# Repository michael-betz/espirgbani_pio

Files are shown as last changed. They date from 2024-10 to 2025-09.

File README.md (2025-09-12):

# The ESP32 Pinball RGB Animation clock

video of the clock in action

Display the time and animations on HUB75 LED panels.

  * Anti aliased fonts
  * Full unicode support (emojis!)
  * Python .ttf font converter tool
  * Alpha blending
  * Background shaders
  * USB-PD powered. Can drive the two 64 x 32 panels at full brightness. The LED turns on if PD negotiation succeeded. Otherwise the clock will run in low-power mode
  * Ambient light sensor

[Video of how it looks like](https://www.youtube.com/watch?v=0dwTC5q5t4M)

[Older writeup](http://yetifrisstlama.blogspot.com/2018/02/the-esp32-pinball-rgb-matrix-animation.html)

# Building
Needs [platform.io](https://platformio.org/) installed.

To install the toolchain and build the project:

```bash
$ pio run
```

Connect USB cable and upload the SPIFFS file system:

```bash
$ pio run -t uploadfs
```

Upload the firmware and show the serial console:

```bash
$ pio run -t upload -t monitor
```

# SD card instructions
Format as FAT32, then copy the following files:
  * `./settings.json`
  * `./animations.img`
  * `./fnt/{d}.fnt`

The .fnt files can be generated from .ttf files with `dev/font_converter.py`.

## `settings.json`
If this file does not exist or cannot be parsed, a new file with default settings will be created.

Once the clock is connected to the network, `settings.json` can be edited in the web-interface at `http://espirgbani.local/`.

```json
{
    "panel_io": {
        "CLK": 13,
        "R1": 22,
        "G1": 23,
        "B1": 21,
        "R2": 18,
        "G2": 19,
        "B2": 5,
        "A": 16,
        "B": 17,
        "C": 2,
        "D": 4,
        "E": 32,
        "LAT": 15,
        "OE_N": 33
    },
    "panel": {
        "test_pattern": true,
        "tp_brightness": 10,
        "low_power_brightness": 20,
        "is_clk_inverted": true,
        "clkm_div_num": 4,
        "max_frame_rate": 30,
        "is_gamma": false,
        "is_locked": true
    },
    "delays": {
        "font": 3600,
        "color": 600,
        "ani": 30,
        "shader": 400
    },
    "power": {
        "mode": 1,
        "offset": 0,
        "divider": 400,
        "max_limit": 100,
        "min_limit": 2,
        "day": {
            "h": 9,
            "m": 0,
            "p": 20
        },
        "night": {
            "h": 22,
            "m": 45,
            "p": 2
        }
    },
    "wifis": {
        "INSERT_SSID": "INSERT_PASSWORD"
    },
    "hostname": "espirgbani",
    "log_level":    {
        "*":    3,
        "httpd_sess":   2,
        "httpd_txrx":   2,
        "httpd_ws": 2,
        "httpd_server": 2,
        "httpd_parse":  2,
        "httpd":    2,
        "spi_master":   2,
        "vfs_fat":  2,
        "wifi": 2
    },
    "timezone": "CET-1CEST,M3.5.0,M10.5.0/3",
    "ntp_host": "pool.ntp.org"
}
```

### `panel_io` section
This section allows you to customize which pins are used on the ESP32 to connect to the panel pins.
The numbers are ESP32 GPIO numbers.

For example, if you run the test-pattern and notice that the red and green colors are swapped,
you can swap their pins on the ESP32 like so:

```json
    "panel_io": {
        "R1": 23,
        "G1": 22,
        "R2": 19,
        "G2": 18
    }
```

### `panel` section
Not all LED panels are the same. Here the timing parameters of the I2S panel driver can be configured.

  * `test_pattern`: if `true`, enters a LED panel test mode instead of normal operation
  * `tp_brightness`: brightness of the test pattern, from 1 to 127. Current draw gets ridiculous for the higher values
  * `low_power_brightness`: maximum brightness if USB-PD negotiation fails (if running from 5 V)
  * `is_clk_inverted`: if `false`, data changes on the rising clock edge. If `true`, data is stable on the rising clock edge (most panels need `true`)
  * `clkm_div_num`: sets the I2S clock divider from 2 to 128. Set it too high and get flicker, too low get ghost pixels. Flicker can be improved at the cost of color depth by reducing `BITPLANE_CNT` in `rgb_led_panel.h`.
  `"clkm_div_num": 4` corresponds to a 10 MHz pixel clock
  * `max_frame_rate`: the global maximum frame-rate limit in [Hz]. The background shader is updated at this rate. If the value is too large, freertos will become unresponsive
  * `is_gamma`: apply gamma correction to LED brightness
  * `is_locked`: stop screen updates while the clock numerals are written. Prevents tearing artifacts at the cost of a short freeze of the background shader

### `delays` section
controls delays between random animations, color and font changes.
They are all specified in [seconds]. The defaults are:

  * Randomize clock font every 3600 s (60 min)
  * Randomize outline color every 600 s (10 min)
  * Play a new pinball animation every 15 s
  * Randomize the background shader every 300 s (5 min). Set `shader` to <= 0 to always have a black background

### `power` section
controls the display brightness. Set the `mode` parameter to 0, 1 or 2 to select the control mode.

__mode 0: constant brightness__

Brightness is always the same and specified in `day.p` as a number from 0 to 127.

__mode 1: use ambient light sensor__

Brightness is set according to the measured ambient light. The sensor returns a number `x` from 0 - 4095 for a measured light level of roughly 10 - 1000 lux.

A linear equation is used to calculate the brightness: `p = (x - offset) / divider`.

The calculated value is limited to the range of `min_limit` to `max_limit` and applied as the panel brightness.

__mode 2: time based switching__

Brightness is set according to the current time. There is a `day` and `night` value, specified in `p` as a number from 0 to 127.

  * In the example, day-mode starts at `9:00` with brightness `20`
  * night-mode starts at `22:45` with brightness `2`

### `wifis` section
Add one or more wifi credentials. The key should be set to the SSID, the value to the wifi password.
If disconnected, the ESP will try to connect to the known wifi with the strongest signal every minute.

If the wifis section is empty or does not exist, the ESP will not try to connect to any wifis.

In any case, push the button on the PCB for > 1 s to toggle between Access Point and station mode.

### `hostname`
The hostname, which is the address where the ESP is reachable from the browser, can be customized here.

### `log_level`
Configure the esp-idf logging library. The key is the logging tag or `*` for everything.

The value the logging level

  * 0 = no logging
  * 1 = errors
  * 2 = warning
  * 3 = info
  * 4 = debug

See https://docs.espressif.com/projects/esp-idf/en/stable/esp32/api-reference/system/log.html

### `timezone`
is the local timezone in [TZ format](https://www.gnu.org/software/libc/manual/html_node/TZ-Variable.html). Look it up [here](https://github.com/nayarsystems/posix_tz_db/blob/master/zones.csv).

### `ntp_host`
The server used for time synchronization.

# TODO
  * fix hardware errors (4 botch wires), use MMC pins for SD card
  * http API support (easy use from curl)
  * wifi button support (access point on button press)
  * mqtt support?
  * update image from serial terminal

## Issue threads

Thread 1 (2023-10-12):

Timezone / settings ?

bipsendk, 2023-10-12:
Trying to understand the settings.json and how it is used in the source....

I cannot locate the place, where the timezone is being used - could you point me in the right direction ?

Also - I think it could be cool if the code was ablt to talk to a MQTT broker, so that some settings could be adjust that way around (e.g. adjusting the brightness of the display).

yetifrisstlama, 2023-10-13:
The timezone setting is a bit hidden in the esp-comms dependency:
https://github.com/yetifrisstlama/esp-comms/blob/f0fe37adfbb356d634fa6ac78435a4e0bac2f3d0/lib/esp-comms/esp_comms.cpp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

Some info on how the ESP handles timezones is given here:
https://docs.espressif.com/projects/esp-idf/en/latest/esp32/api-reference/system/system_time.html#timezones

Mqtt would indeed be pretty sweet to have, also to display short messages.

bipsendk, 2023-10-13:
Thanks - that got me a bit of info...

I'm no expert in programming myself, but if MQTT at some point would be added, I guess it is a question of being able to specify MQTT server/port - and create the required stuff for the device having auto-discoverable properties.
This would make the project more attractive for people with smarthome setups :-)

Closed 2023-11-01.

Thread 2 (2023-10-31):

Artifacts on panel

bipsendk, 2023-10-31:
The artifacts as seen on the attached picture - are they to be expected, or should I try to increase the blanks value in the json file?

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

michael-betz, 2023-11-01:
Hi bipsendk, glad to see you got the code running :)

I've noticed the same kind of ghosting on my panels when driven at maximum brightness.
My solution was to mount the panels behind some tinted acrylic, which makes the ghosting much less visible.

Maybe it can be fixed in the signal generation by putting some dead-time in the right place. Unfortunately I don't have the hardware setup right now to try that out.

You can also try playing with the parameters in the settings.json:

  * Reduce the brightness with `power.day.p` and `power.night.p`
  * Increase `extra_blank`, but I think I remember this didn't have an effect on my panels
  * Increase `clkm_div_num` to lower the output clock frequency
  * If you get flicker, you can try to reduce `BITPLANE_CNT` in rgb_led_panel.h to lower color resolution and increase refresh rate

Good luck and let me know how it goes,
Michael

bipsendk, 2023-11-01:
I will try to adjust brightness - but not quite sure if that will resolve the issue (just make it less visible).
Anyway - as I am not the only one seeing it, it is not something related directly to my hardware - so far, so good,

On the other hand, when trying to connect to the web interface, I get http error 500 .. I am using the IP address in the URL, not the hostname - but I guess that shouldn't be a problem.
Can it be an issue with the json config file ? I have not yet tried to remove it, to see if that changes anything.
Is it possible to add more logging a compile time - so I can get a hint on what is going on - and perhaps where in the code ?

michael-betz, 2023-11-02:
Hmm that's a strange one. Just to be sure, did you flash the filesystem?
```bash
$ pio run -t uploadfs
```

bipsendk, 2023-11-02:
That was the missing thing... As I am using pio via VSCode on Windows, I expected that to happen during the upload of the firmware - but apparently that needs to be handled as a separate task. Thanks

michael-betz, 2025-01-07:
The ghosting issue is completely resolved now in the current version of the software. This was done by enabling the LEDs (setting the /OE signal low) in the middle of the frame update cycle instead of at the beginning / end. This maximizes the delay between the edge of the Latch pulse and the /OE low period, giving the signals on the panel some time to stabilize.

Closed 2023-11-02.

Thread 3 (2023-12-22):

LDR / Photo resistor

bipsendk, 2023-12-22:
Is the LDR / Photo resistor still supported in the new version of the software ?

As multiple versions exists of LDR (different values), I guess some sort of "calibration" will have to be done - unless you are sure to get the right LDR ?

michael-betz, 2025-01-07:
The ambient light sensor is supported now in the software. See power-mode 1 in the [README.md](https://github.com/michael-betz/espirgbani_pio#power-section)

Closed 2025-01-07.

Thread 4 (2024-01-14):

Pin re-assignment

bipsendk, 2024-01-14:
For the HUB75 connection - is it possible to swap the different pins in the header file - to better suit the pinout of a Wemos D1 ESP32 ? - or is special attention needed on some of the pins ?

Closed 2024-12-27.

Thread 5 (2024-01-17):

Newer framework when compiling

bipsendk, 2024-01-17:
I have managed to get the code compiled on a newer framework, also with the fseek "hack"/optimizartion enabled in the framework.

One issue remains, though - it seems like the partitions.bin file isn't created.

I am not sure what part actually creates this one.

for lib_deps I have had to change to this - not sure if that affects the generation of the data:

```
lib_deps =
	https://github.com/me-no-dev/AsyncTCP.git
	https://github.com/me-no-dev/ESPAsyncWebServer.git
	https://github.com/yetifrisstlama/esp-comms.git

```

Let me know if I should share the modified files

bipsendk, 2024-01-18:
FYI - the result of the build with the newer framework - not quite sure why it cannot read the SD card, as it works OK with the same framework for the fseek test:

```
I (29) boot: ESP-IDF 4.4.6 2nd stage bootloader
I (29) boot: compile time 20:34:44
I (29) boot: Multicore bootloader
I (32) boot: chip revision: v3.0
I (36) boot.esp32: SPI Speed      : 40MHz
I (41) boot.esp32: SPI Mode       : DIO
I (45) boot.esp32: SPI Flash Size : 4MB
I (50) boot: Enabling RNG early entropy source...
I (55) boot: Partition Table:
I (59) boot: ## Label            Usage          Type ST Offset   Length
I (66) boot:  0 nvs              WiFi data        01 02 00009000 00005000
I (73) boot:  1 otadata          OTA data         01 00 0000e000 00002000
I (81) boot:  2 app0             OTA app          00 10 00010000 00140000
I (88) boot:  3 app1             OTA app          00 11 00150000 00140000
I (96) boot:  4 spiffs           Unknown data     01 82 00290000 00160000
I (103) boot:  5 coredump         Unknown data     01 03 003f0000 00010000
I (111) boot: End of partition table
I (115) esp_image: segment 0: paddr=00010020 vaddr=3f400020 size=215b0h (136624) map
I (173) esp_image: segment 1: paddr=000315d8 vaddr=3ffb0000 size=032b4h ( 12980) load
I (179) esp_image: segment 2: paddr=00034894 vaddr=40080000 size=0b784h ( 46980) load
I (198) esp_image: segment 3: paddr=00040020 vaddr=400d0020 size=ad920h (710944) map
I (456) esp_image: segment 4: paddr=000ed948 vaddr=4008b784 size=09b6ch ( 39788) load
I (483) boot: Loaded app from partition at offset 0x10000
I (483) boot: Disabling RNG early entropy source...
I (494) cpu_start: Multicore app
I (495) cpu_start: Pro cpu up.
I (495) cpu_start: Starting app cpu, entry point is 0x40081d84
I (485) cpu_start: App cpu up.
I (515) cpu_start: Pro cpu start user code
I (515) cpu_start: cpu freq: 160000000
I (515) cpu_start: Application information:
I (519) cpu_start: Project name:     espirgbani_pio-master-NEW
I (526) cpu_start: App version:      1
I (530) cpu_start: Compile time:     Jan 17 2024 20:30:37
I (536) cpu_start: ELF file SHA256:  57173bc45eb927f1...
I (542) cpu_start: ESP-IDF:          4.4.6
I (547) cpu_start: Min chip rev:     v0.0
I (552) cpu_start: Max chip rev:     v3.99
I (557) cpu_start: Chip rev:         v3.0
I (562) heap_init: Initializing. RAM available for dynamic allocation:
I (569) heap_init: At 3FFAE6E0 len 00001920 (6 KiB): DRAM
I (575) heap_init: At 3FFC5A00 len 0001A600 (105 KiB): DRAM
I (581) heap_init: At 3FFE0440 len 00003AE0 (14 KiB): D/IRAM
I (587) heap_init: At 3FFE4350 len 0001BCB0 (111 KiB): D/IRAM
I (594) heap_init: At 400952F0 len 0000AD10 (43 KiB): IRAM
I (601) spi_flash: detected chip: generic
I (605) spi_flash: flash io: dio
I (611) cpu_start: Starting scheduler on PRO CPU.
I (0) cpu_start: Starting scheduler on APP CPU.
[    49][W][main.cpp:71] setup(): reset reason: 12, heap: 211120, min_heap: 211112
I (207) gpio: GPIO[33]| InputEn: 1| OutputEn: 1| OpenDrain: 0| Pullup: 0| Pulldown: 0| Intr:0
I (208) gpio: GPIO[35]| InputEn: 1| OutputEn: 0| OpenDrain: 0| Pullup: 0| Pulldown: 0| Intr:0
I (216) gpio: GPIO[32]| InputEn: 1| OutputEn: 1| OpenDrain: 0| Pullup: 0| Pulldown: 0| Intr:0
I (225) gpio: GPIO[14]| InputEn: 1| OutputEn: 1| OpenDrain: 0| Pullup: 0| Pulldown: 0| Intr:0
[   256][E][json_settings.cpp:53] readFileDyn(): fopen(/sd/settings.json, rb) failed: Invalid argument
[   258][W][json_settings.cpp:128] set_settings_file(): writing default-settings to /sd/settings.json
[   271][E][json_settings.cpp:136] set_settings_file(): could not copy /spiffs/default_settings.json to /sd/settings.json: Invalid argument
[   282][E][json_settings.cpp:53] readFileDyn(): fopen(/sd/settings.json, rb) failed: Invalid argument
[   292][E][json_settings.cpp:164] jGetI(): max_frame_rate is not a number, falling back to 30
[   301][E][json_settings.cpp:184] jGetB(): column_swap is not a bool, falling back to false
[   310][E][json_settings.cpp:164] jGetI(): latch_offset is not a number, falling back to 0
[   319][V][rgb_led_panel.cpp:76] init_rgb(): latch_offset = 127
[   325][E][json_settings.cpp:164] jGetI(): extra_blank is not a number, falling back to 1
[   334][E][json_settings.cpp:164] jGetI(): clkm_div_num is not a number, falling back to 4
[   343][V][rgb_led_panel.cpp:84] init_rgb(): clkm_div_num = 4
[   350][E][json_settings.cpp:184] jGetB(): is_clk_inverted is not a bool, falling back to true
[   360][I][rgb_led_panel.cpp:124] init_rgb(): I2S setup done.
[   375][E][json_settings.cpp:154] jGetS(): wifi_ssid is not a string, falling back to RG47C-0
[   375][E][json_settings.cpp:154] jGetS(): hostname is not a string, falling back to ESP-PINBALL
[   385][E][json_settings.cpp:154] jGetS(): wifi_pw is not a string, falling back to DemsPi8!av63ippo#
I (385) wifi:wifi driver task: 3ffdd930, prio:23, stack:6656, core=0
I (1420) wifi:wifi firmware version: 1ba8b6a
I (1420) wifi:wifi certification version: v7.0
I (1421) wifi:config NVS flash: enabled
I (1421) wifi:config nano formating: disabled
I (1425) wifi:Init data frame dynamic rx buffer num: 32
I (1430) wifi:Init management frame dynamic rx buffer num: 32
I (1435) wifi:Init management short buffer num: 32
I (1440) wifi:Init dynamic tx buffer num: 32
I (1444) wifi:Init static rx buffer size: 1600
I (1448) wifi:Init static rx buffer num: 4
I (1452) wifi:Init dynamic rx buffer num: 32
I (1457) wifi_init: rx ba win: 6
I (1460) wifi_init: tcpip mbox: 32
I (1464) wifi_init: udp mbox: 6
I (1468) wifi_init: tcp mbox: 6
I (1471) wifi_init: tcp tx win: 5744
I (1476) wifi_init: tcp rx win: 5744
I (1480) wifi_init: tcp mss: 1440
I (1484) wifi_init: WiFi IRAM OP enabled
I (1489) wifi_init: WiFi RX IRAM OP enabled
[   491][D][WiFiGeneric.cpp:1039] _eventCallback(): Arduino Event: 0 - WIFI_READY
I (1503) phy_init: phy_version 4771,450c73b,Aug 16 2023,11:03:10
I (1584) wifi:mode : sta (a0:b7:65:62:ed:98)
I (1585) wifi:enable tsf
00;3;377mm[[      558683]][[VV][][WWiiFiFiGGeenenerriicc..cpcppp::9734]0 ]s e_ta_redsupi_nion_teervfeanct_cb()) SCA Stgrreng 0ta
[   589][D][WiFiGeneric.cpp:1039] _eventCallback(): Arduino Event: 2 - STA_START
tion static IP: 0.0.0.0, MASK: 0.0.0.0, GW: 0.0.0.0
I (1600) wifi:Set ps type: 1

[   607][I][esp_comms.cpp:104] init_comms(): This is ESP-PINBALL, connecting to RG47C-0
I (1616) gpio: GPIO[0]| InputEn: 1| OutputEn: 0| OpenDrain: 0| Pullup: 1| Pulldown: 0| Intr:0
I (1622) wifi:new:<9,0>, old:<1,0>, ap:<255,255>, sta:<9,0>, prof:1
I (1633) wifi:state: init -> auth (b0)
I (1637) wifi:state: auth -> assoc (0)
I (1644) wifi:state: assoc -> run (10)
I (1663) wifi:connected with RG47C-0, aid = 22, channel 9, BW20, bssid = 28:c7:ce:1e:f8:c0
I (1664) wifi:security: WPA2-PSK, phy: bgn, rssi: -62
I (1670) wifi:pm start, type: 1

I (1673) wifi:<ba-add>idx:0 (ifx:0, 28:c7:ce:1e:f8:c0), tid:0, ssn:2612, winSize:64
[   669][V][WiFiGeneric.cpp:355] _arduino_event_cb(): STA Connected: SSID: RG47C-0, BSSID: 28:c7:ce:1e:f8:c0, Channel: 9, Auth: WPA2_PSK
[   686][D][WiFiGeneric.cpp:1039] _eventCallback(): Arduino Event: 4 - STA_CONNECTED
I (1724) wifi:AP's beacon interval = 104448 us, DTIM period = 2
[  1691][V][WiFiGeneric.cpp:369] _arduino_event_cb(): STA Got New IP:192.168.225.153
[  1693][D][WiFiGeneric.cpp:1039] _eventCallback(): Arduino Event: 7 - STA_GOT_IP
[  1698][D][WiFiGeneric.cpp:1102] _eventCallback(): STA IP: 192.168.225.153, MASK: 255.255.255.0, GW: 192.168.225.202
0;32mI (2696) esp_netif_handlers: sta ip: 192.168.225.153, mask: 255.255.255.0, gw: 192.168.225.202
[  1723][I][esp_comms.cpp:115] init_comms(): Initializing SNTP
[  2725][E][json_settings.cpp:154] jGetS(): hostname is not a string, falling back to ESP-PINBALL
[  2725][E][json_settings.cpp:184] jGetB(): enable_ota is not a bool, falling back to false
[  2749][E][json_settings.cpp:154] jGetS(): timezone is not a string, falling back to PST8PDT
[  2749][I][esp_comms.cpp:144] init_comms(): Setting timezone to TZ = PST8PDT
[  2755][I][esp_comms.cpp:152] init_comms(): Local Time: Wed Jan 17 11:43:16 2024 (1705520596)
[  2764][W][main.cpp:93] setup(): after COMMS, heap: 100644, min_heap: 99668
[  2772][E][json_settings.cpp:184] jGetB(): test_pattern is not a bool, falling back to true
[  2781][W][main.cpp:101] setup(): RGB test-pattern mode!!!
[  2787][E][json_settings.cpp:164] jGetI(): tp_brightness is not a number, falling back to 10
[  2797][E][json_settings.cpp:164] jGetI(): tp_brightness is not a number, falling back to 10
[  2816][D][frame_buffer.cpp:206] tp_task(): Diagonal
Guru Meditation Error: Core  0 panic'ed (LoadStoreError). Exception was unhandled.

Core  0 register dump:
PC      : 0x400d9b47  PS      : 0x00060430  A0      : 0x800d9c66  A1      : 0x3ffe8450
A2      : 0x3ffe0454  A3      : 0x3ffe30c0  A4      : 0x401772a0  A5      : 0x00000000
A6      : 0x3ffe0454  A7      : 0x3ffe3968  A8      : 0x800d9bba  A9      : 0x3ffe8430
A10     : 0x3ffe30c0  A11     : 0x40000de8  A12     : 0x3ffe2abc  A13     : 0x3ffe3b9a
A14     : 0x0000000d  A15     : 0x00000000  SAR     : 0x0000001a  EXCCAUSE: 0x00000003
EXCVADDR: 0x40000df7  LBEG    : 0x400014fd  LEND    : 0x4000150d  LCOUNT  : 0xfffffffd

Backtrace: 0x400d9b44:0x3ffe8450 0x400d9c63:0x3ffe84b0 0x400d9d69:0x3ffe84f0 0x400d9f5d:0x3ffe8550 0x4015d519:0x3ffe8570 0x4015d56d:0x3ffe85a0 0x4015d5b1:0x3ffe85c0 0x4015d76e:0x3ffe85e0 0x4015d83f:0x3ffe8600 0x4008c3a1:0x3ffe8630
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

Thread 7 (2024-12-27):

PCB - add connectors for external USB / SD-card ?

bipsendk, 2024-12-27:
Regarding the "new" version of the PCB - have you considered adding e.g. JST-XH header for "external" USB connector (6-pin) - and JST-PH header for using an "external" SD-Card PCB (arduino-style) ? That will increase flexibility if/when using the PCB with different sizes of HUB75 panels and placing them inside a 3D printed enclosure.

bipsendk, 2024-12-28:
Like this:
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

michael-betz, 2025-01-07:
Ahh interesting idea! Feel free to implement it, using the existing layout as a starting point.

The new PCB was especially designed to fit nicely right into the typical P2.5 panels.

Another idea to gain some flexibility is to solder a right-angled pin header on the PCB and then use the flat cable which comes with the panels to connect them to the PCB.

bipsendk, 2025-01-23:
The comment in to-do about changing pins for the SDcard - would that be to GPIO 12/13/14/15 for the MOSI/MISO/CLK/CS - or 5/18/19/23  ?
As far as I remember, there was a challenge with pin 12 during boot ?

michael-betz, 2025-01-23:
Hi,

you can have a look at the schematic in the REV3 branch:

https://github.com/michael-betz/espirgbani_pio/blob/rev3/pcb/pdf/rgb.pdf

I've chosen the pins to make use of the SD-MMC block in the chip.

I've convinced myself that this should work out of the box in 2-wire mode.
But please review!

For 4-wire mode, the pullup on GPIO12 needs to be added __after__ the efuse in the ESP32 has been burned for 3.3 V flash operation.

bipsendk, 2025-02-09:
Just wondering - would an ESP32-S3 be able to run the code? It comes in versions with more GPIO pins, and if more pins were available, perhaps a battery-backed RTC chip/module could be added to the setup to make sure the clock also could/would run in case of lack of internet access upon bootup.

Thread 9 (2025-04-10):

Ambient light sensor

bipsendk, 2025-04-10:
I am looking at the rev 3 code, and wonder a bit about the ambient light sensor...

	// 8x mode, actually 0 .. 32k now
	//   10 lux,   3 uA, 0.03 V,   50, Twilight, candle light
	//   50 lux,         0.17 V,  284, Street light at night
	//  100 lux,  33 uA, 0.33 V,  550, Dark museum
	// 1000 lux, 330 uA, 3.30 V, 4095, Bright office lightning

If 100 lux will let 33 uA pass - and the resistor is 24K - wouldn't the voltage be like 0.792V - and not 0.33V ?

The reason is, that listed ambient light sensor is a bit hard to find at a reasonable price at my location - where SIC433-02 is a bit easier to get.
That sensor has typically 220uA at 100lux - so in order to match 0.33V (if correct) would have to use a 1.5K resistor, and if matching 0.792V the resistor would have to be 3.6K ...

To get 0.33V with 33uA, the resistor would have to be 10K - or am I missing something ?

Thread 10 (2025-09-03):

FR: Disable PD pin

bipsendk, 2025-09-03:
In case you use "external" power decoy, the power good signal may not be avilable.

Would it be possible to modify the code in such a way, that of if GPIO_PD_BAD is not defined in common.h - then this "input" would not be used in the code

bipsendk, 2025-09-08:
But will there still be a risk, that the LPWR text will be triggered ?

Closed 2025-09-08.

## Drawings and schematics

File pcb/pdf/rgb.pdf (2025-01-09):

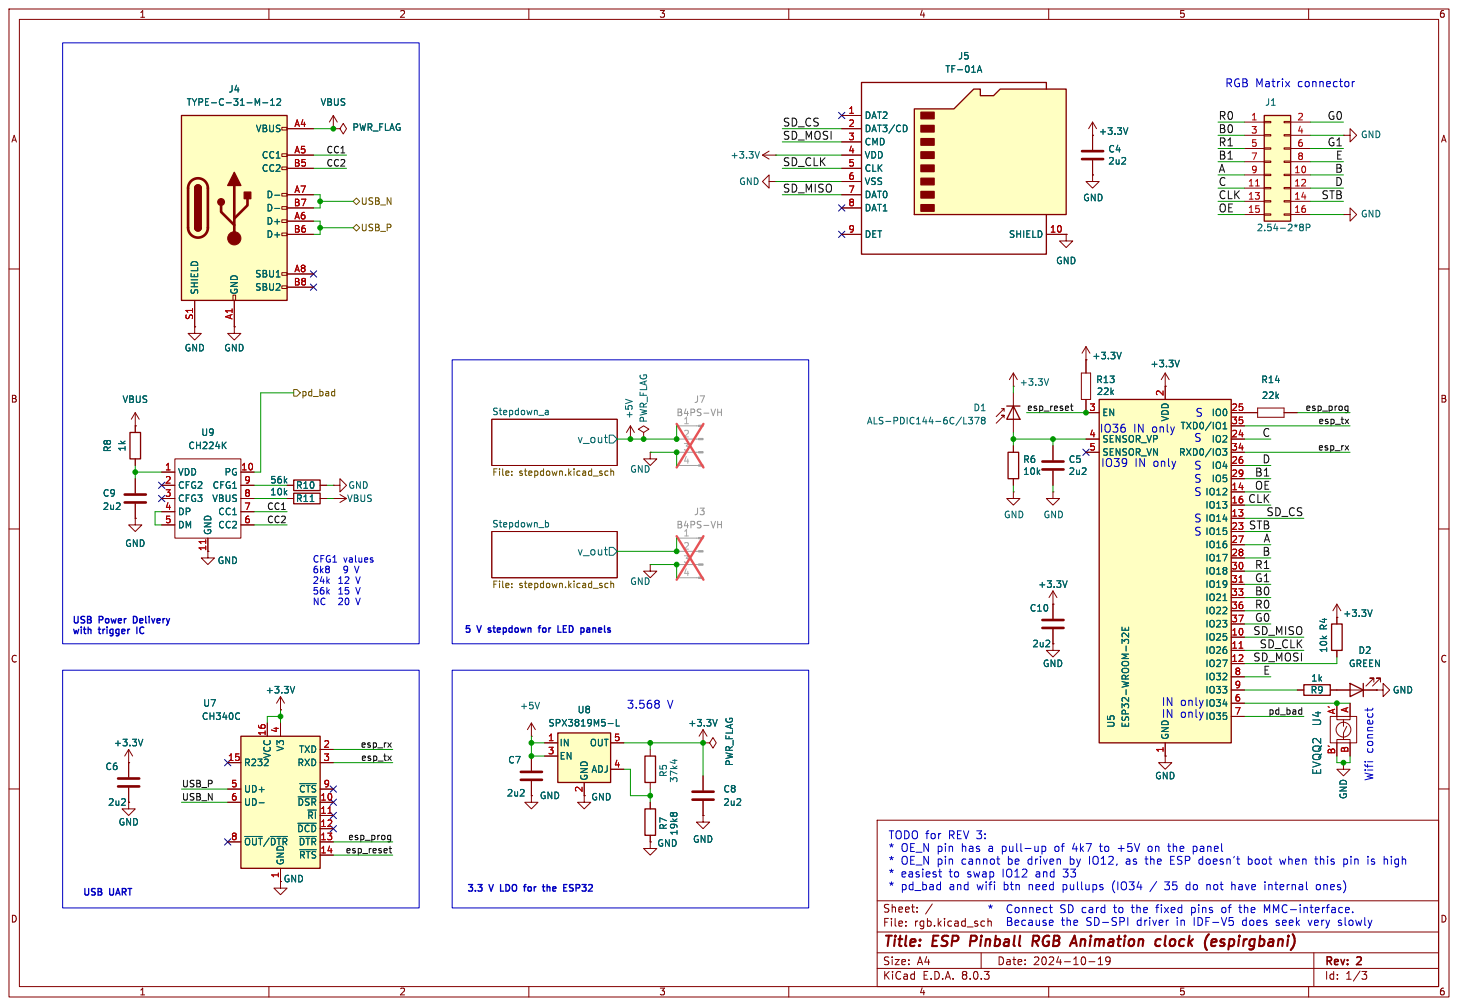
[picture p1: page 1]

5 V stepdown for LED panels R11 10k U9 CH224K

4 UD+ 5 UD- 6 ~{OUT}/~{DTR} 8 ~{CTS}9 U7 CH340C GND GND

2 EN 3 ADJ 4 OUT 5 U8 SPX3819M5-L GND

1 ~{DSR} 10 ~{RI} 11 ~{DCD} 12 ~{DTR} 13 ~{RTS} 14 R232 15 VCC 16 TXD 2 RXD 3 V3

4 UD+ 5 UD- 6 ~{OUT}/~{DTR} 8 ~{CTS}9 +3.3V C6

2 EN 3 ADJ 4 OUT 5 GND

* easiest to swap IO12 and 33

Id: 1/3 Title: ESP Pinball RGB Animation clock (espirgbani) File: rgb.kicad_sch Sheet: /

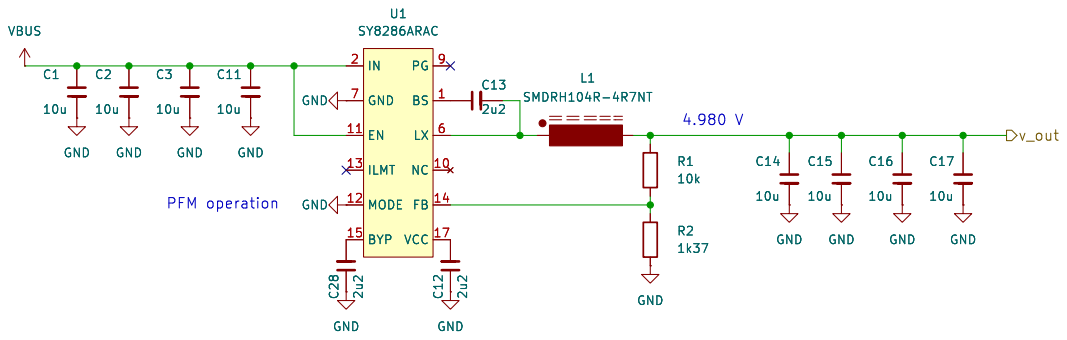
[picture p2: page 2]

Id: 2/3 Title: File: stepdown.kicad_sch Sheet: /Stepdown_a/

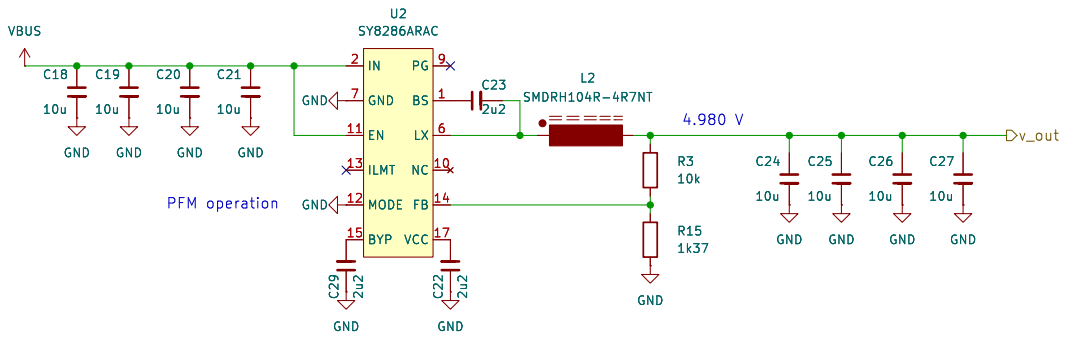
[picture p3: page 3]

Id: 3/3 Title: File: stepdown.kicad_sch Sheet: /Stepdown_b/

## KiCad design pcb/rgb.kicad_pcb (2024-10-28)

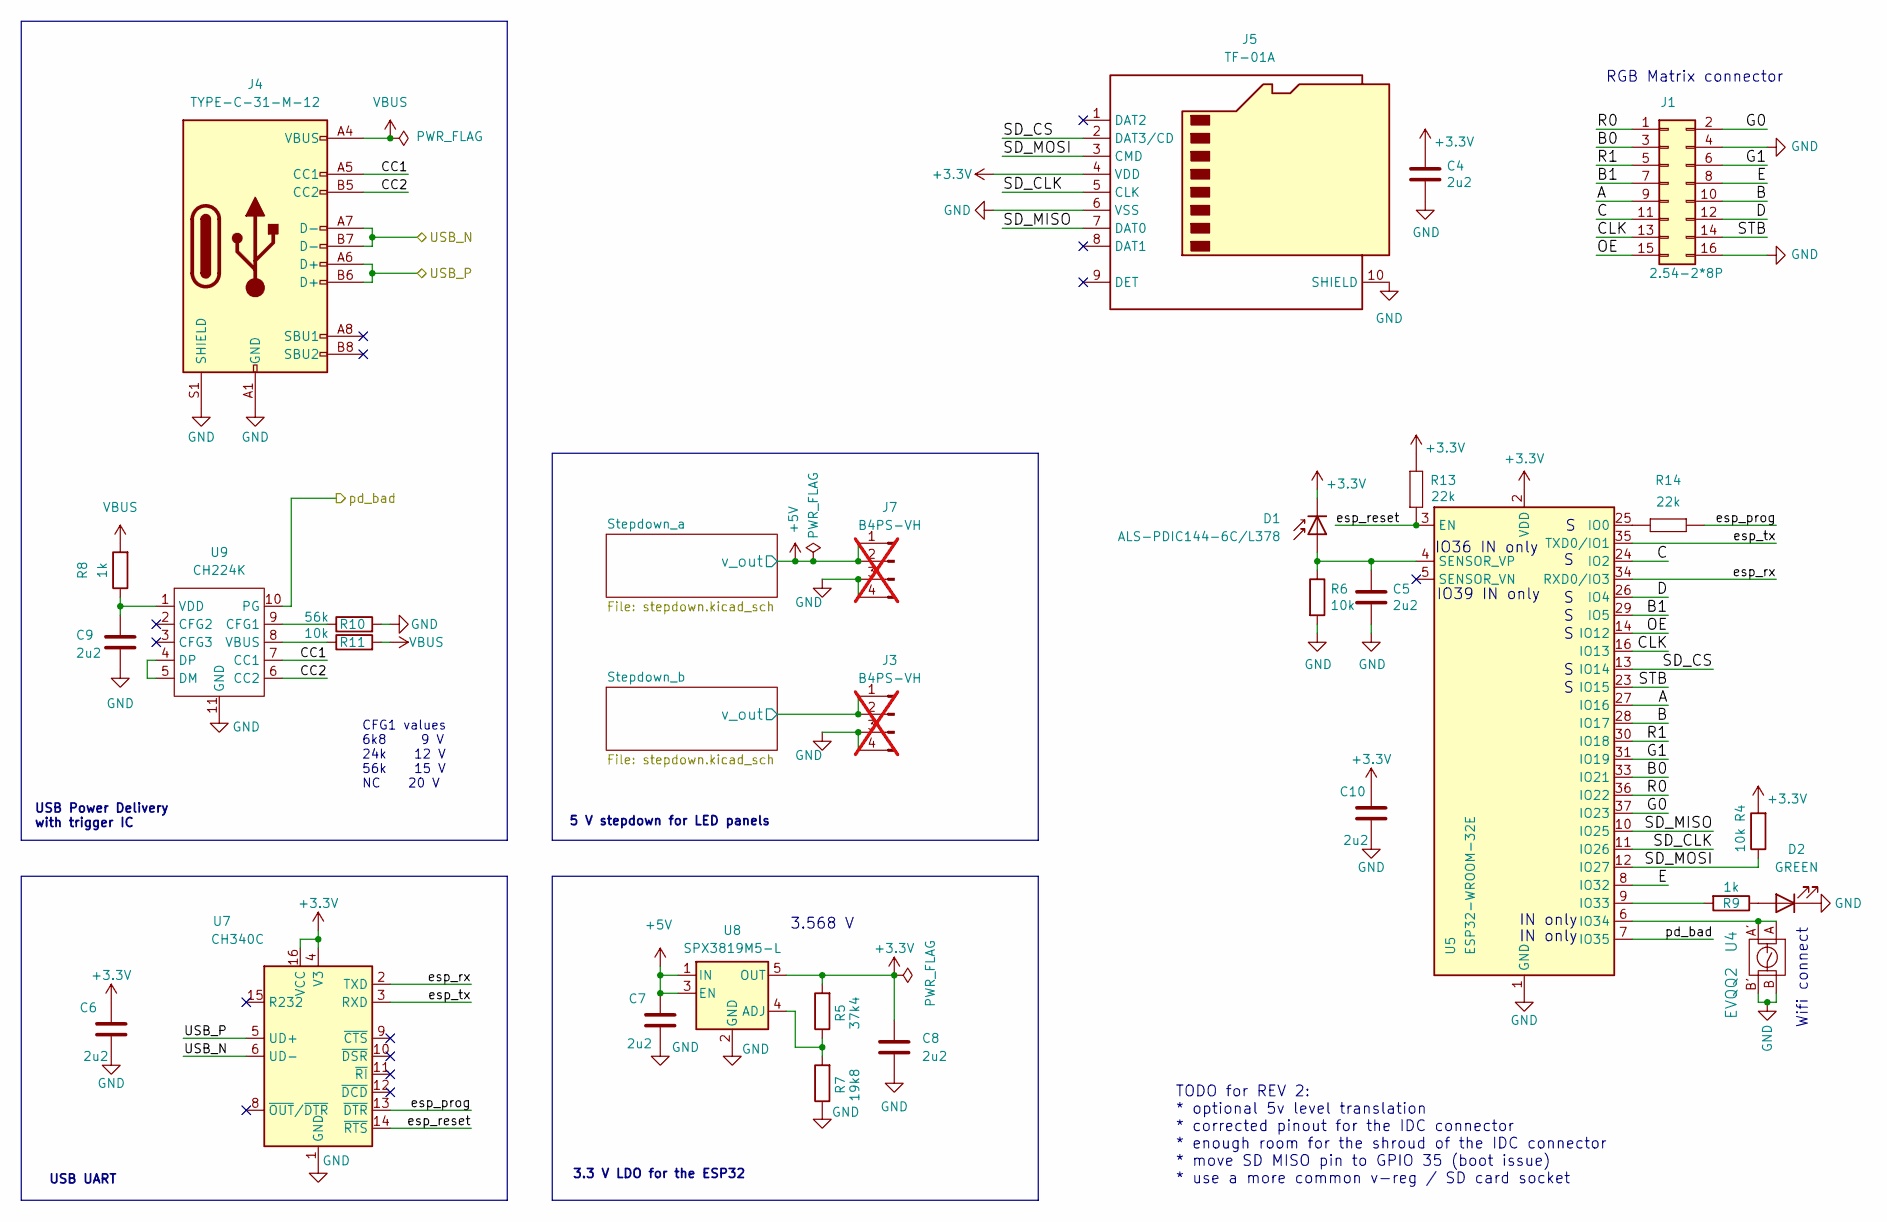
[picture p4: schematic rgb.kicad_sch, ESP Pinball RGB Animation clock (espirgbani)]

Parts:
C4, C5, C6, C7, C8, C9, C10: 2u2; C_0603_1608Metric
D1: ALS-PDIC144-6C/L378; LED_D3.0mm_Horizontal_O3.81mm_Z6.0mm
D2: GREEN; LED_0603_1608Metric
J1: 2.54-2*8P; PinSocket_2x08_P2.54mm_Vertical
J3, J7: B4PS-VH; PinSocket_1x04_P2.54mm_Vertical; JLCPN C157996; not fitted
J4: TYPE-C-31-M-12; USB_C_Receptacle_GCT_USB4105-xx-A_16P_TopMnt_Horizontal
J5: TF-01A
R4, R6, R11: 10k; R_0603_1608Metric
R5: 37k4; R_0603_1608Metric
R7: 19k8; R_0603_1608Metric
R8, R9: 1k; R_0603_1608Metric
R10: 56k; R_0603_1608Metric
R13, R14: 22k; R_0603_1608Metric
U4: EVQQ2
U5: ESP32-WROOM-32E; ESP32-WROOM-32D
U7: CH340C; SOIC-16_3.9x9.9mm_P1.27mm
U8: SPX3819M5-L; SOT-23-5
U9: CH224K; SSOP-10-1EP_3.9x4.9mm_P1.00mm

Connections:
+3.3V: C4.1, C6.2, C8.1, C10.2, D1.1 (K), J5.4 (VDD), R4.2, R5.2, R13.2, U5.2 (VDD), U7.4 (V3), U7.16 (VCC), U8.5 (OUT)
+5V: C7.2, J7.1, J7.2, U8.1 (IN), U8.3 (EN); also elsewhere on the board
/A: J1.9, U5.27 (IO16)
/B: J1.10, U5.28 (IO17)
/B0: J1.3, U5.33 (IO21)
/B1: J1.7, U5.29 (IO5)
/C: J1.11, U5.24 (IO2)
/CC1: J4.A5 (CC1), U9.7 (CC1)
/CC2: J4.B5 (CC2), U9.6 (CC2)
/CLK: J1.13, U5.16 (IO13)
/D: J1.12, U5.26 (IO4)
/E: J1.8, U5.8 (IO32)
/G0: J1.2, U5.37 (IO23)
/G1: J1.6, U5.31 (IO19)
/OE: J1.15, U5.14 (IO12)
/R0: J1.1, U5.36 (IO22)
/R1: J1.5, U5.30 (IO18)
/SD_CLK: J5.5 (CLK), U5.11 (IO26)
/SD_CS: J5.2 (DAT3/CD), U5.13 (IO14)
/SD_MISO: J5.7 (DAT0), U5.10 (IO25)
/SD_MOSI: J5.3 (CMD), R4.1, U5.12 (IO27)
/STB: J1.14, U5.23 (IO15)
/Stepdown_b/v_out: J3.1, J3.2; also elsewhere on the board
/USB_N: J4.A7 (D-), J4.B7 (D-), U7.6 (UD-)
/USB_P: J4.A6 (D+), J4.B6 (D+), U7.5 (UD+)
/esp_prog: R14.1, U7.13 (~DTR)
/esp_reset: R13.1, U5.3 (EN), U7.14 (~RTS)
/esp_rx: U5.34 (RXD0/IO3), U7.2 (TXD)
/esp_tx: U5.35 (TXD0/IO1), U7.3 (RXD)
/pd_bad: U5.7 (IO35), U9.10 (PG)
GND: C4.2, C5.2, C6.1, C7.1, C8.2, C9.2, C10.1, D2.1 (K), J1.4, J1.16, J3.3, J3.4, J4.A1 (GND), J4.A12 (GND), J4.B1 (GND), J4.B12 (GND), J4.S1 (SHIELD), J5.6 (VSS), J5.10 (SHIELD), J7.3, J7.4, R6.2, R7.1, R10.2, U4.B, U4.B', U5.1 (GND), U5.15 (GND), U5.38 (GND), U5.39 (GND), U7.1 (GND), U8.2 (GND), U9.11 (GND); also elsewhere on the board
unnamed: C5.1, D1.2 (A), R6.1, U5.4 (SENSOR_VP)
unnamed: D2.2 (A), R9.1
unnamed: R14.2, U5.25 (IO0)
unnamed: R9.2, U5.9 (IO33)
unnamed: U4.A, U4.A', U5.6 (IO34)
unnamed: R5.1, R7.2, U8.4 (ADJ)
unnamed: R10.1, U9.9 (CFG1)
unnamed: U9.4 (DP), U9.5 (DM)
unnamed: R11.1, U9.8 (VBUS)
unnamed: C9.1, R8.1, U9.1 (VDD)
VBUS: J4.A4 (VBUS), J4.A9 (VBUS), J4.B4 (VBUS), J4.B9 (VBUS), R8.2, R11.2; also elsewhere on the board

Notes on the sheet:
IO36 IN only
IN only
TODO for REV 2: * optional 5v level translation * corrected pinout for the IDC connector * enough room for the shroud of the IDC connector * move SD MISO pin to GPIO 35 (boot issue) * use a more common v-reg / SD card socket
USB Power Delivery with trigger IC
3.3 V LDO for the ESP32
CFG1 values 6k8 9 V 24k 12 V 56k 15 V NC 20 V
IO39 IN only
RGB Matrix connector
5 V stepdown for LED panels
3.568 V
Wifi connect
USB UART

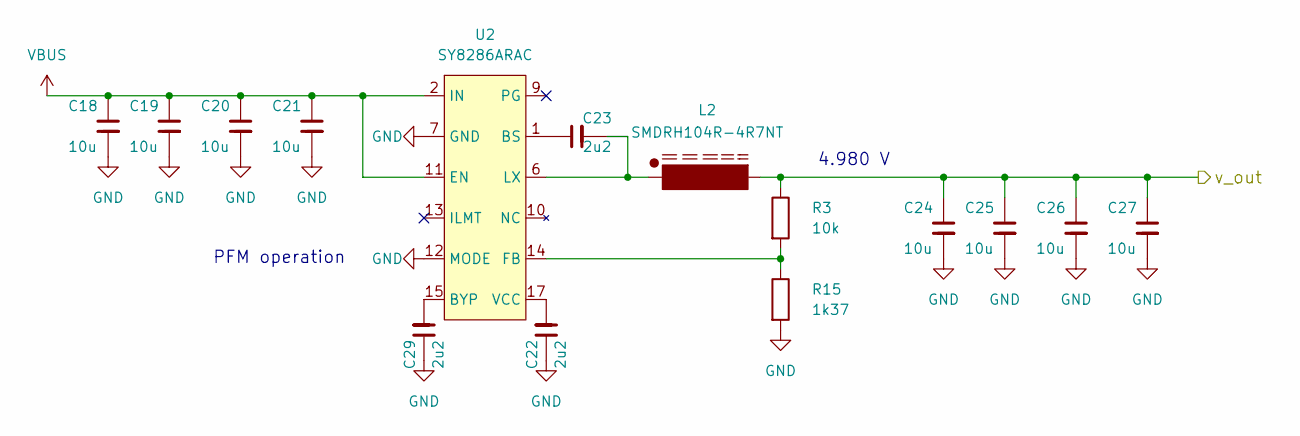
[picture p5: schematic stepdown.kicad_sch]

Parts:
C18, C19, C20, C21, C24, C25, C26, C27: 10u; C_1206_3216Metric; JLCPN C13585
C22, C23, C29: 2u2; C_0603_1608Metric
L2: SMDRH104R-4R7NT; JLCPN C44850
R3: 10k; R_0603_1608Metric
R15: 1k37; R_0603_1608Metric
U2: SY8286ARAC; QFN-20-1EP_3x3mm_P0.45mm_EP1.6x1.6mm

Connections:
/Stepdown_b/v_out: C24.2 (K), C25.2 (K), C26.2 (K), C27.2 (K), L2.1, R3.1; also elsewhere on the board
GND: C18.1 (A), C19.1 (A), C20.1 (A), C21.1 (A), C22.2 (K), C24.1 (A), C25.1 (A), C26.1 (A), C27.1 (A), C29.2 (K), R15.2, U2.7 (GND), U2.8 (GND), U2.12 (MODE), U2.18 (GND), U2.21 (GND); also elsewhere on the board
unnamed: C22.1 (A), U2.17 (VCC)
unnamed: C23.1 (A), L2.2, U2.6 (LX), U2.19 (LX), U2.20 (LX)
unnamed: C23.2 (K), U2.1 (BS)
unnamed: C29.1 (A), U2.15 (BYP)
unnamed: R3.2, R15.1, U2.14 (FB)
VBUS: C18.2 (K), C19.2 (K), C20.2 (K), C21.2 (K), U2.2 (IN), U2.3 (IN), U2.4 (IN), U2.5 (IN), U2.11 (EN); also elsewhere on the board

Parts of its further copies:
C1, C2, C3, C11, C14, C15, C16, C17: 10u; C_1206_3216Metric; JLCPN C13585
C12, C13, C28: 2u2; C_0603_1608Metric
L1: SMDRH104R-4R7NT; JLCPN C44850
R1: 10k; R_0603_1608Metric
R2: 1k37; R_0603_1608Metric
U1: SY8286ARAC; QFN-20-1EP_3x3mm_P0.45mm_EP1.6x1.6mm

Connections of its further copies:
+5V: C14.2 (K), C15.2 (K), C16.2 (K), C17.2 (K), L1.1, R1.1; also elsewhere on the board
GND: C1.1 (A), C2.1 (A), C3.1 (A), C11.1 (A), C12.2 (K), C14.1 (A), C15.1 (A), C16.1 (A), C17.1 (A), C28.2 (K), R2.2, U1.7 (GND), U1.8 (GND), U1.12 (MODE), U1.18 (GND), U1.21 (GND); also elsewhere on the board
unnamed: C12.1 (A), U1.17 (VCC)
unnamed: C13.1 (A), L1.2, U1.6 (LX), U1.19 (LX), U1.20 (LX)
unnamed: C13.2 (K), U1.1 (BS)
unnamed: C28.1 (A), U1.15 (BYP)
unnamed: R1.2, R2.1, U1.14 (FB)
VBUS: C1.2 (K), C2.2 (K), C3.2 (K), C11.2 (K), U1.2 (IN), U1.3 (IN), U1.4 (IN), U1.5 (IN), U1.11 (EN); also elsewhere on the board

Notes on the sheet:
4.980 V
PFM operation

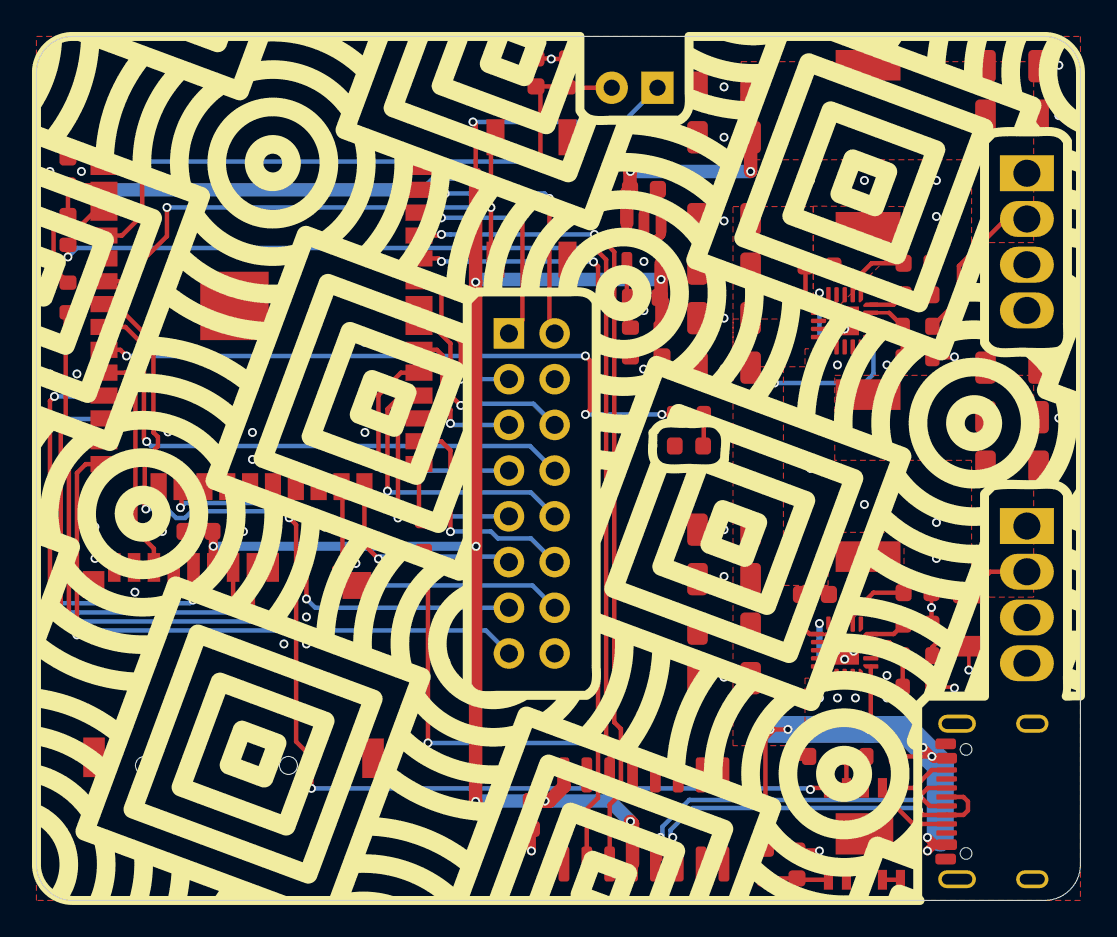
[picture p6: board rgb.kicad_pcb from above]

Board: 2 copper layers, 58.0 x 48.0 mm, 59 parts (1 on the bottom side), 52 nets.

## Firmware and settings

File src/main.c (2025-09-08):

// The ESP32 Pinball Animation Clock

#include "freertos/FreeRTOS.h"
#include "freertos/task.h"
#include "rom/rtc.h"
#include <dirent.h>
#include <errno.h>
#include <stdio.h>
#include <string.h>
#include <sys/types.h>

#include "driver/sdmmc_host.h"
#include "esp_http_server.h"
#include "esp_log.h"
#include "esp_spiffs.h"
#include "esp_vfs_fat.h"
#include "sdmmc_cmd.h"

#include "esp_wifi.h"
#include "json_settings.h"
#include "static_ws.h"
#include "wifi.h"

#include "animations.h"
#include "common.h"
#include "font.h"
#include "frame_buffer.h"
#include "rgb_led_panel.h"
#include "shaders.h"

static const char *T = "MAIN";

TaskHandle_t t_backg = NULL;
TaskHandle_t t_pinb = NULL;

static esp_err_t mount_sd_card(const char *path) {
	sdmmc_host_t host = SDSPI_HOST_DEFAULT();
	host.max_freq_khz = 26000; // [kHz]

	spi_bus_config_t bus_cfg = {
		.mosi_io_num = GPIO_SD_MOSI,
		.miso_io_num = GPIO_SD_MISO,
		.sclk_io_num = GPIO_SD_CLK,
		.quadwp_io_num = -1,
		.quadhd_io_num = -1,
	};
	ESP_ERROR_CHECK(spi_bus_initialize(host.slot, &bus_cfg, SDSPI_DEFAULT_HOST)
	);
	gpio_pullup_en(GPIO_SD_MISO);
	gpio_pullup_en(GPIO_SD_CS);

	sdmmc_card_t *card = NULL;

	sdspi_device_config_t device_cfg = SDSPI_DEVICE_CONFIG_DEFAULT();
	device_cfg.gpio_cs = GPIO_SD_CS;
	device_cfg.host_id = host.slot;

	esp_vfs_fat_sdmmc_mount_config_t mount_config = {
		.format_if_mount_failed = true,
		.max_files = 4,
	};

	esp_err_t ret = esp_vfs_fat_sdspi_mount(
		"/sd", &host, &device_cfg, &mount_config, &card
	);

	// sdmmc_host_t host = SDMMC_HOST_DEFAULT();
	// sdmmc_slot_config_t slot_config = SDMMC_SLOT_CONFIG_DEFAULT();
	// slot_config.width = 1;

	// slot_config.clk = GPIO_SD_CLK;
	// slot_config.cmd = GPIO_SD_MOSI;
	// slot_config.d0 = GPIO_SD_MISO;

	// // Enable internal pullups on enabled pins. The internal pullups
	// // are insufficient however, please make sure 10k external pullups are
	// // connected on the bus. This is for debug / example purpose only.
	// slot_config.flags |= SDMMC_SLOT_FLAG_INTERNAL_PULLUP;

	// ESP_LOGI(T, "Mounting filesystem");
	// ret = esp_vfs_fat_sdmmc_mount(mount_point, &host, &slot_config,
	// &mount_config, &card);

	// if (ret != ESP_OK) {
	//     if (ret == ESP_FAIL) {
	//         ESP_LOGE(T, "Failed to mount filesystem. ")
	//     } else {
	//         ESP_LOGE(T, "Failed to initialize the card (%s). ",
	//         esp_err_to_name(ret));
	//         // check_sd_card_pins(&config, pin_count);
	//     }
	//     return;
	// }

	if (ret == ESP_OK) {
		// Card has been initialized, print its properties
		sdmmc_card_print_info(stdout, card);
	} else {
		ESP_LOGE(
			T, "Failed to mount SD card. Continuing in test-pattern mode."
		);
	}
	return ret;
}

void list_files(const char *path) {
	ESP_LOGI(T, "Listing %s", path);
	DIR *dir = opendir(path);
	if (dir == NULL)
		return;

	while (true) {
		struct dirent *de = readdir(dir);
		if (!de)
			break;
		ESP_LOGI(T, "    %s", de->d_name);
	}

	closedir(dir);
}

void init_log() {
	const cJSON *jLog = NULL;
	const cJSON *jLogs = jGet(getSettings(), "log_level");

	cJSON_ArrayForEach(jLog, jLogs) {
		if (!cJSON_IsNumber(jLog)) {
			ESP_LOGW(T, "log_level: ignoring %s (not an int)", jLog->string);
			continue;
		}
		esp_log_level_set(jLog->string, jLog->valueint);
	}
}

// This handles websocket traffic, needs ESP-IDF > 4.2.x
static esp_err_t ws_handler(httpd_req_t *req) {
	static char ret_buffer[64];
	int ret_len = -1;

	if (req->method == HTTP_GET) {
		ESP_LOGI(T, "WS handshake");
		return ESP_OK;
	}

	// Copy the received payload into local buffer
	httpd_ws_frame_t wsf = {0};
	esp_err_t ret = httpd_ws_recv_frame(req, &wsf, 0);
	if (ret != ESP_OK)
		return ret;

	wsf.payload = malloc(wsf.len);
	if (!wsf.payload)
		return ESP_ERR_NO_MEM;

	ret = httpd_ws_recv_frame(req, &wsf, wsf.len);
	if (ret != ESP_OK) {
		free(wsf.payload);
		return ret;
	}

	if (wsf.type == HTTPD_WS_TYPE_TEXT && wsf.len > 0) {
		// Process the payload
		ESP_LOGV(T, "ws_callback(%c, %d)", wsf.payload[0], wsf.len);
		switch (wsf.payload[0]) {
		case 'a':
			if (wsf.len > 1 && wsf.payload[1] == '1')
				// dump complete log buffer
				wsDumpRtc(req, true);
			else
				// dump updates only
				wsDumpRtc(req, false);
			break;

		case 'b':
			// read / write settings.json
			settings_ws_handler(req, &wsf.payload[1], wsf.len - 1);
			if (wsf.len > 1)
				init_log();
			break;

		case 'r':
			esp_wifi_disconnect();
			set_brightness(0);
			vTaskDelay(100 / portTICK_PERIOD_MS);
			esp_restart();
			break;

		case 'h':
			ret_len = snprintf(
				ret_buffer, sizeof(ret_buffer),
				"h{\"heap\": %ld, \"min_heap\": %ld}", esp_get_free_heap_size(),
				esp_get_minimum_free_heap_size()
			);
			break;
		}
	}
	free(wsf.payload);

	// Send reply if needed
	if (ret_len >= 0) {
		if (ret_len > sizeof(ret_buffer))
			ret_len = sizeof(ret_buffer);

		httpd_ws_frame_t ret_wsf = {0};
		ret_wsf.type = HTTPD_WS_TYPE_TEXT;
		ret_wsf.payload = (uint8_t *)ret_buffer;
		ret_wsf.len = ret_len;
		httpd_ws_send_frame(req, &ret_wsf);
	}
	return ESP_OK;
}

void app_main(void) {
	// forward serial characters to web-console
	web_console_init();

	//------------------------------
	// init hardware
	//------------------------------
	// Power LED will be enabled by updateFrame loop if PD is not bad
	gpio_config_t cfg_o = {
		.pin_bit_mask = (1LL << GPIO_LED), .mode = GPIO_MODE_OUTPUT
	};
	ESP_ERROR_CHECK(gpio_config(&cfg_o));
	gpio_set_level(GPIO_LED, 0);

	// PD_BAD GPIO. If this is high we don't have juice. Run in low power mode
	// Wifi button will switch to hotspot mode
	gpio_config_t cfg_i = {
#ifdef GPIO_PD_BAD
		.pin_bit_mask = (1LL << GPIO_PD_BAD) | (1LL << GPIO_WIFI),
#else
		.pin_bit_mask = (1LL << GPIO_WIFI),
#endif
		.mode = GPIO_MODE_INPUT,
		.pull_up_en = GPIO_PULLUP_ENABLE,
		.pull_down_en = GPIO_PULLDOWN_DISABLE
	};
	ESP_ERROR_CHECK(gpio_config(&cfg_i));

	// report initial status
	ESP_LOGW(
		T, "reset reason: %d, heap: %ld, min_heap: %ld",
		rtc_get_reset_reason(0), esp_get_free_heap_size(),
		esp_get_minimum_free_heap_size()
	);

	// Mount spiffs for *.html and default_settings.json
	esp_vfs_spiffs_conf_t conf = {
		.base_path = "/spiffs",
		.partition_label = "filesys",
		.max_files = 4,
		.format_if_mount_failed = false
	};
	ESP_ERROR_CHECK(esp_vfs_spiffs_register(&conf));
	list_files("/spiffs");

	// Mount SD for animations, fonts and for settings.json
	esp_err_t ret = mount_sd_card("/sd");
	if (ret == ESP_OK) {
		list_files("/sd");
		// Load settings.json from SD card, try to create file if it doesn't
		// exist
		set_settings_file("/sd/settings.json", "/spiffs/default_settings.json");
	} else {
		// No SD card, load default settings and go to test-pattern mode
		set_settings_file("/spiffs/default_settings.json", NULL);
	}

	init_log();

	// init I2S driven rgb - panel
	init_rgb();

	// init web-server
	initWifi();
	tryJsonConnect();
	startWebServer(ws_handler);

	//------------------------------
	// Display test-patterns
	//------------------------------
	// only if enabled in json
	cJSON *jPanel = jGet(getSettings(), "panel");
	if (jGetB(jPanel, "test_pattern", true)) {
		ESP_LOGW(T, "RGB test-pattern mode!!!");
		set_brightness(MAX(0, jGetI(jPanel, "tp_brightness", 10)));
		tp_task(NULL);
	}

	//-----------------------------------
	// Startup animated background layer
	//-----------------------------------
	// this one calls updateFrame and hence
	// sets the global maximum frame-rate
	xTaskCreatePinnedToCore(
		&aniBackgroundTask, "bck", 1024 * 4, NULL, 1, &t_backg, 1
	);

	//---------------------------------
	// Draw animations and clock layer
	//---------------------------------
	xTaskCreatePinnedToCore(
		&aniPinballTask, "pin", 1024 * 8, NULL, 0, &t_pinb, 0
	);

	vTaskDelete(NULL);
}

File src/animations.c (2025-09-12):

#include "animations.h"
#include "common.h"
#include "esp_log.h"
#include "esp_timer.h"
#include "fast_hsv2rgb.h"
#include "font.h"
#include "frame_buffer.h"
#include "json_settings.h"
#include "rom/rtc.h"
#include "wifi.h"

#include "esp_adc/adc_cali.h"
#include "esp_adc/adc_cali_scheme.h"
#include "esp_adc/adc_oneshot.h"
#include "esp_wifi.h"

#include <errno.h>
#include <stdint.h>
#include <stdlib.h>
#include <string.h>
#include <sys/stat.h>
#include <time.h>

static const char *T = "ANIMATIONS";

// Reads the filehader and fills `fh`
static int getFileHeader(FILE *f, fileHeader_t *fh) {
	char tempCh[3];

	if (f == NULL || fh == NULL)
		return -1;

	fseek(f, 0x00000000, SEEK_SET);
	fread(tempCh, 3, 1, f);
	if (memcmp(tempCh, "DGD", 3) != 0) {
		ESP_LOGE(T, "Invalid file header!");
		return -1;
	}
	fread(&fh->nAnimations, 2, 1, f);
	fh->nAnimations = SWAP16(fh->nAnimations);
	fseek(f, 0x000001EF, SEEK_SET);
	fread(&fh->buildStr, 8, 1, f);
	fh->buildStr[8] = '\0';

	ESP_LOGI(T, "nAnimations: %d, buildStr: %s", fh->nAnimations, fh->buildStr);
	return 0;
}

// Fills the headerEntry struct with data.
// Specify an `headerIndex` from 0 to nAnimations
static int _cur_hi = 0;
static int readHeaderEntry(FILE *f, headerEntry_t *h, int headerIndex) {
	if (f == NULL || h == NULL)
		return -1;

	_cur_hi = headerIndex;

	// Copys header info into h. Note that h->nFrameEntries must be freed!
	fseek(f, HEADER_OFFS + HEADER_SIZE * headerIndex, SEEK_SET);
	fread(h, sizeof(*h), 1, f);
	h->name[31] = '\0';
	h->frameHeader = NULL;
	h->animationId = SWAP16(h->animationId);
	h->byteOffset = SWAP32(h->byteOffset) * HEADER_SIZE;
	// Exract frame header
	frameHeaderEntry_t *fh = (frameHeaderEntry_t *)malloc(
		sizeof(frameHeaderEntry_t) * h->nFrameEntries
	);
	if (fh == NULL) {
		ESP_LOGE(T, "Memory allocation error!");
		return -1;
	}
	h->frameHeader = fh;
	fseek(f, h->byteOffset, SEEK_SET);
	for (int i = 0; i < h->nFrameEntries; i++) {
		fread(&fh->frameId, 1, 1, f);
		fread(&fh->frameDur, 1, 1, f);
		// Hack to sort out invalid headers
		if (fh->frameDur <= 0 || fh->frameId > h->nStoredFrames) {
			ESP_LOGE(T, "Invalid header!");
			return -1;
		}
		fh++;
	}
	return 0;
}

// seek the file f to the beginning of a specific animation frame
static void seekToFrame(FILE *f, int byteOffset, int frameId) {
	// without fast-seek enabled, this sometimes takes hundreds of ms,
	// resulting in choppy animation playback
	// http://www.elm-chan.org/fsw/ff/doc/lseek.html
	if (f == NULL || frameId <= 0)
		return;
	byteOffset += DISPLAY_WIDTH * DISPLAY_HEIGHT * (frameId - 1) / 2;
	fseek(f, byteOffset, SEEK_SET);
}

// play a single animation, start to finish
static void playAni(FILE *f, headerEntry_t *h) {
	int64_t seek_time = 0;
	int max_seek_time = 0;

	int64_t draw_time = 0;
	int max_draw_time = 0;
	int sum_draw_time = 0;

	if (f == NULL || h == NULL || h->nFrameEntries == 0)
		return;

	// get a random color
	uint8_t r, g, b;
	fast_hsv2rgb_32bit(
		RAND_AB(0, HSV_HUE_MAX), HSV_SAT_MAX, HSV_VAL_MAX, &r, &g, &b
	);
	unsigned color = SRGBA(r, g, b, 0xFF);

	// pre-seek the file to beginning of frame
	frameHeaderEntry_t fh = h->frameHeader[0];
	seekToFrame(f, h->byteOffset + HEADER_SIZE, fh.frameId);
	unsigned cur_delay = fh.frameDur;
	TickType_t xLastWakeTime = xTaskGetTickCount();

	for (int i = 0; i < h->nFrameEntries; i++) {
		draw_time = esp_timer_get_time();
		if (fh.frameId <= 0)
			setAll(2, 0xFF000000); // invalid frame = translucent black
		else
			setFromFile(f, 2, color);
		draw_time = esp_timer_get_time() - draw_time;
		sum_draw_time += draw_time;
		if (draw_time > max_draw_time)
			max_draw_time = draw_time;

		// get the next frame ready in advance
		if (i < h->nFrameEntries - 1) {
			fh = h->frameHeader[i + 1];

			seek_time = esp_timer_get_time();
			seekToFrame(f, h->byteOffset + HEADER_SIZE, fh.frameId);
			seek_time = esp_timer_get_time() - seek_time;
			if (seek_time > max_seek_time)
				max_seek_time = seek_time;
		}

		// clip minimum delay to avoid skipping frames
		if (cur_delay < g_f_del)
			cur_delay = g_f_del;

		// wait for N ms, measured from last call to vTaskDelayUntil()
		vTaskDelayUntil(&xLastWakeTime, cur_delay / portTICK_PERIOD_MS);
		cur_delay = fh.frameDur;
	}
	ESP_LOGD(
		T, "%d, %s, f: %d / %d, d: %d ms, seek: %d ms, draw: %d / %d ms",
		_cur_hi, h->name, h->nStoredFrames, h->nFrameEntries,
		h->frameHeader->frameDur, max_seek_time / 1000,
		sum_draw_time / h->nFrameEntries / 1000, max_draw_time / 1000
	);
}

// blocks while rendering a pinball animation, with fade-out.
// takes care of loading header data
static void run_animation(FILE *f, unsigned aniId) {
	TickType_t xLastWakeTime;
	headerEntry_t myHeader;

	if (f == NULL)
		return;

	readHeaderEntry(f, &myHeader, aniId);
	playAni(f, &myHeader);
	free(myHeader.frameHeader);
	myHeader.frameHeader = NULL;

	// Keep a single frame displayed for a bit
	if (myHeader.nStoredFrames <= 3 || myHeader.nFrameEntries <= 3)
		vTaskDelay(3000 / portTICK_PERIOD_MS);

	// Fade out the frame
	uint32_t nTouched = 1;
	xLastWakeTime = xTaskGetTickCount();
	while (nTouched) {
		nTouched = fadeOut(2, 10);
		vTaskDelayUntil(&xLastWakeTime, g_f_del / portTICK_PERIOD_MS);
	}
}

adc_oneshot_unit_handle_t adc_handle;

void init_light_sensor() {
	adc_oneshot_unit_init_cfg_t init_config = {
		.unit_id = ADC_UNIT_1,
	};
	ESP_ERROR_CHECK(adc_oneshot_new_unit(&init_config, &adc_handle));

	//-------------ADC1 Config---------------//
	adc_oneshot_chan_cfg_t config = {
		.atten = ADC_ATTEN_DB_12,	 // VMAX = 2450
		.bitwidth = ADC_BITWIDTH_12, // 12 bit, DMAX = 4095
	};
	// ADC_UNIT_1, ADC_CHANNEL_0 is connected to SENSOR_VP pin
	ESP_ERROR_CHECK(
		adc_oneshot_config_channel(adc_handle, ADC_CHANNEL_0, &config)
	);
}

int get_light_sensor() {
	// 8x mode, actually 0 .. 32k now
	//   10 lux,   3 uA, 0.03 V,   50, Twilight, candle light
	//   50 lux,         0.17 V,  284, Street light at night
	//  100 lux,  33 uA, 0.33 V,  550, Dark museum
	// 1000 lux, 330 uA, 3.30 V, 4095, Bright office lightning
	int sum = 0;
	for (unsigned i = 0; i < 8; i++) {
		int tmp = 0;
		adc_oneshot_read(adc_handle, ADC_CHANNEL_0, &tmp);
		sum += tmp;
	}
	return sum;
}
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

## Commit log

2020-06-09 smooth animations, even without fast_seek
    * no more lost chars in web-console
    * replace 4 x spaces with tabs
    [i2s_parallel.c]
2020-06-13 get rid of separate clock task
    * combined task for pinball animations and clock update
    * saves a lot of precious heap and stack
    * make max. frame-rate and layer sync. configurable
2020-06-15 pin the 2 tasks to 2 cores
2020-06-16 frame_buffer: pre-calculate 4 bit shades
2020-06-16 add radial laser shader
2020-06-17 fine tune laser shader
2020-06-27 aaLine: mix colors
    removes artifacts when lines are drawn close together,
    like in the laser shader
2023-11-02 common.h: set GPIO_SD_MISO to 12, compatible with REV1 PCB
    in the next revision of the PCB I would use GPIO35, but this
    doesn't exist yet (except for hacking REV1)
    [common.h]
2024-10-19 add first try at rev 2 of the schematic
    [rgb.kicad_pcb, rgb.kicad_sch, stepdown.kicad_sch]
2024-10-19 pcb: exploration
    [rgb.kicad_pcb, rgb.kicad_sch, stepdown.kicad_sch]
2024-10-20 initial routing done
    [rgb.kicad_pcb, rgb.kicad_sch, stepdown.kicad_sch]
2024-10-22 turn esp by 90 deg
    rip-up, re-route
    [rgb.kicad_pcb, rgb.kicad_sch]
2024-10-22 optimize pinout
    [rgb.kicad_pcb, rgb.kicad_sch, stepdown.kicad_sch]
2024-10-23 finish routing
    [rgb.kicad_pcb]
2024-10-23 solve DRC errors
    [rgb.kicad_pcb]
2024-10-23 put a cool pattern on the bottom silk
    [rgb.kicad_pcb, rgb.kicad_sch, stepdown.kicad_sch]
2024-10-23 mostly ready for production. 18 $ / board in qty. 5
    [rgb.kicad_pcb, rgb.kicad_sch]
2024-10-23 add pattern to top silkscreen, order
    [rgb.kicad_pcb, rgb.kicad_sch, stepdown.kicad_sch]
2024-10-28 pcb: increase esp32 voltage slightly
    [rgb.kicad_pcb, rgb.kicad_sch]
2024-10-28 first step at getting rid of the arduino dependencies
2024-11-04 add ambient light sensor
2024-11-05 finish and document ambient light mode
    add custom partition layout
    [partitions.csv]
2024-11-05 fix a compiler warning
    [i2s_parallel.c]
2024-11-05 implement low power mode
2024-11-05 add the power LED gpio
2024-11-05 led pins don't react yet
2024-11-06 fix i2s_parallel.c io_config function. clang-format align
    [animations.c, common.h, fast_hsv2rgb_32bit.c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]
2024-11-06 hardware bug, swap IO 12 and 33
    [rgb.kicad_sch]
2024-11-07 rework the websocket stuff
    [animations.c, main.c, rgb_led_panel.c]
2024-11-12 update panel driver. doesn't work yet
    [i2s_parallel.c, rgb_led_panel.c]
2024-11-13 add log level and min. brightness to settings
    works but sth. is wrong with the SD card
    [animations.c, common.h, frame_buffer.c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]
2024-11-14 fix heap corruption in json_settings()
    [main.c, rgb_led_panel.c]
2024-11-15 remove the framebuffer lock. It did not have any advantage.
2024-11-16 make websocket logging work more robustly
    the browser now polls the log-buffer every second (query - response)
    [partitions.csv]
2024-11-16 add optional gamma correction
    [frame_buffer.c, main.c]
2024-11-18 misc. bug fixes
    * run in TP mode without SD card
    * Use more accurate clock for RTC (80 MHz)
    * add single panel mode which centers the text on the
    first panel
    [animations.c, frame_buffer.c, main.c]
2024-11-18 massive re-write of the whole font system. 10x faster now
    * get rid of bmfont dependency to generate font files
    * use similar font format as esp32_crt but serialized
    in a file on sd card
    * full unicode support (emojis, etc)
    * outline support
    * don't use .bmp file anymore (slow, inefficient)
    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
2024-11-19 test converting the first batch on fonts
    * fix bug in glyphToBuffer() when pixels get skipped
    [animations.c]
2024-11-21 add framebuffer lock to layer 2 again
2025-01-09 update schematic .pdf
2025-01-09 schematic: one more item for the todo list
    [rgb.kicad_sch, stepdown.kicad_sch]
2025-05-13 Add log-levels to settings.json, fix float overflow for lasers shader.
2025-05-13 switch espressif32 from 6.9 to 6.10, add HW_REV3
2025-09-08 animations.c: display the WIFI state decently on the panel
    * also make the push-button toggle between station and AP mode
2025-09-08 common.h: make GPIO_PD_BAD optional
    if not defined, the clock will never enter low-power mode
